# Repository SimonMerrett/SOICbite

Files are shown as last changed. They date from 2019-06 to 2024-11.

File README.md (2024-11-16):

# SOICbite
A compact PCB footprint which allows SOIC test clips to be used as a space-efficient programming and debugging connector

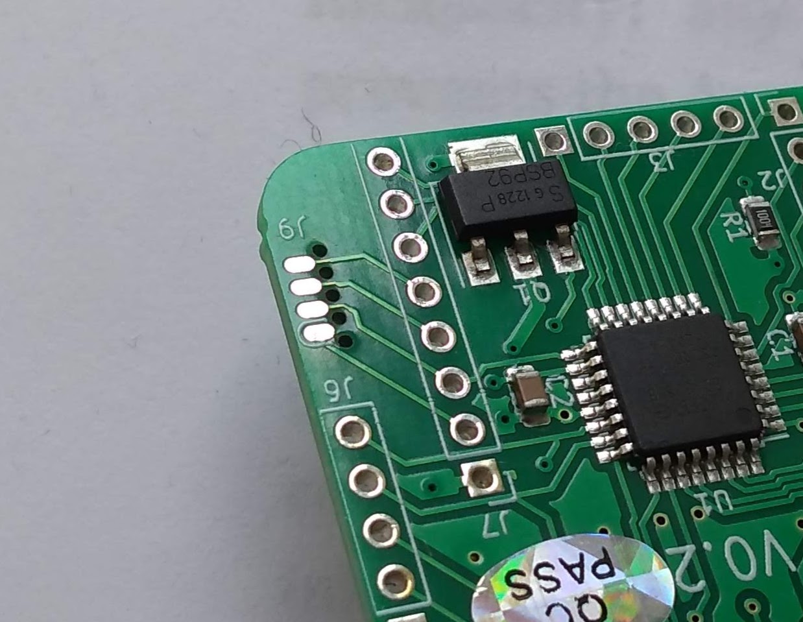
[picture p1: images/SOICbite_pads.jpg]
PBC pads


This is the repository for a hackaday.io project on this connector footprint.

It's cheaper than a Tag Connect and may even be smaller. 

This has been tested as a SPI programmer on AVRs and a UART programmer on ESP32.

The footprints are available in the following formats:

- Kicad (.kicad_mod)
- Eagle XML (.lbr)
- gEDA PCB (.fp)
- pcb-rnd (.lht)

and more formats are welcome.

You do need to [adjust your SOIC-8 test clip](https://github.com/SimonMerrett/SOICbite/blob/master/HOWTO_mod_clip.md) so that it will close enough to press the contact pins against the PCB pads. See the photos in the images folder - about 1mm will do to start with. Depending on your pin configuration, you need to make sure opposing contacts don't touch each other when no PCB is between them. 

Also, you may need to use short sections of thin traces to escape the pads between the NPTH.

# Pin assignment

If you don't know where to start, here are a few suggestions for pin assignments of some interfaces:

| Pin | UART | SPI | SWIM | SWD | ESP8266 | USB | I2C | PIC ICSP | JTAG | SWD + UART |
| --- | ---- | --- | ---- | ----- | --- | --- | --- | --- | ---- | --- |
| 1 | Vcc  | Vcc | Vcc  | Vcc | Vcc | Vcc | Vcc | Vcc | Vcc  | Vcc |
| 2 | RX2  | CS | | | GPIO0 | D-  | | Vpp | TMS  | RX |
| 3 | TX2  | | | | GPIO2 | D+  | | | TCK  | TX |
| 4 | GND  | GND | GND  | GND | GND | GND | GND | GND | GND  | GND |
| 5 | RX | MOSI/MOMI | SWIM | SWDIO | RX | | SDA | DAT | TDI  | SWDIO |
| 6 | TX | MISO | | SWO | TX | | | AUX | TDO  | SWO |
| 7 | CTS  | SCK/CLK | | SWCLK | CH_PD | | SCL | CLK | RTCK | SWCLK |
| 8 | RTS  | RST | NRST | NRST  | RST | ID  | | | NRST | NRST |

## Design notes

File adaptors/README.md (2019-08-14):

# Adaptors

Opinionated boards to breakout the SOICbite connections to standard interface pin arrangements.

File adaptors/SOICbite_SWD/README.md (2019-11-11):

# SOICbite SWD Breakout

SOICbite to SWD breakout board:

1. Standard Cortex Debug connector - VCC, GND, SWDIO, SWCLK, SWO and NRST pins are broken out
2. 4-Pin 2.54" Header - VCC, SWDIO, SWCLK, GND are broken out

## 3D Renders

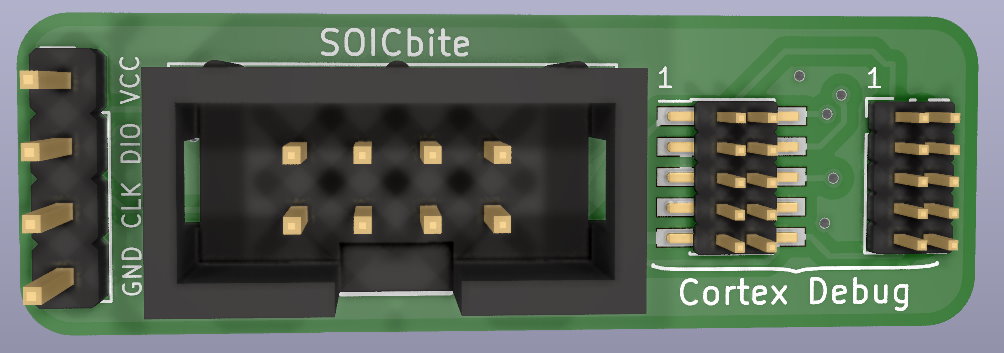
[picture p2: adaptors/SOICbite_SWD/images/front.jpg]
Board front

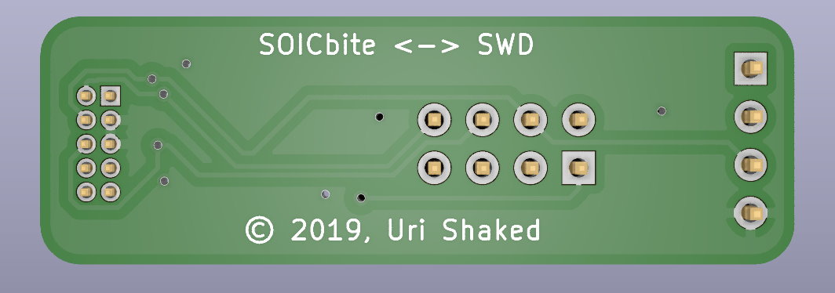
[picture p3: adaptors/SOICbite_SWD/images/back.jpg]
Board back


## Images

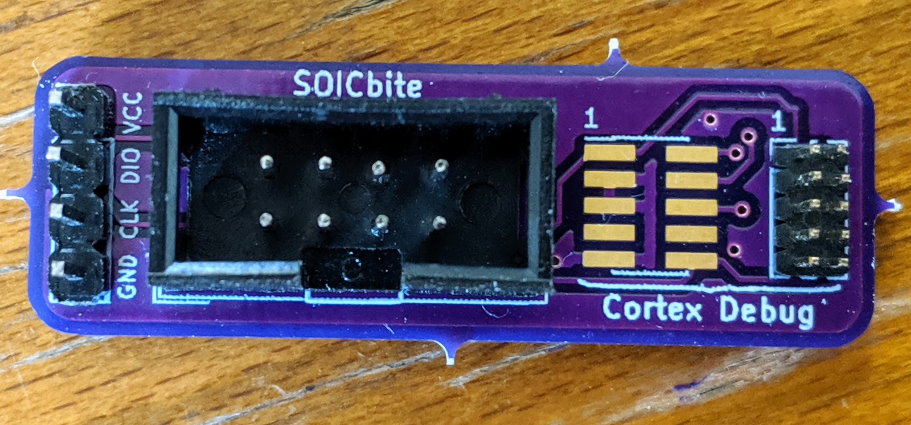
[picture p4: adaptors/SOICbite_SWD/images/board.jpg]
Board image


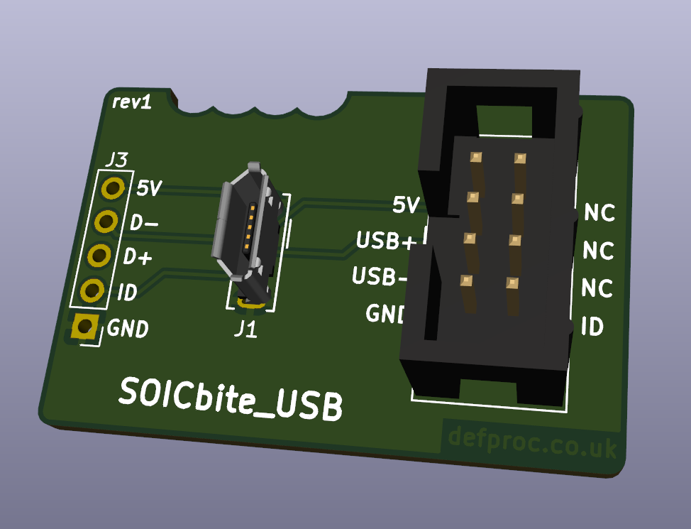
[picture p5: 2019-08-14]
adaptors/SOICbite_USB/images/rev1_3D_front.png

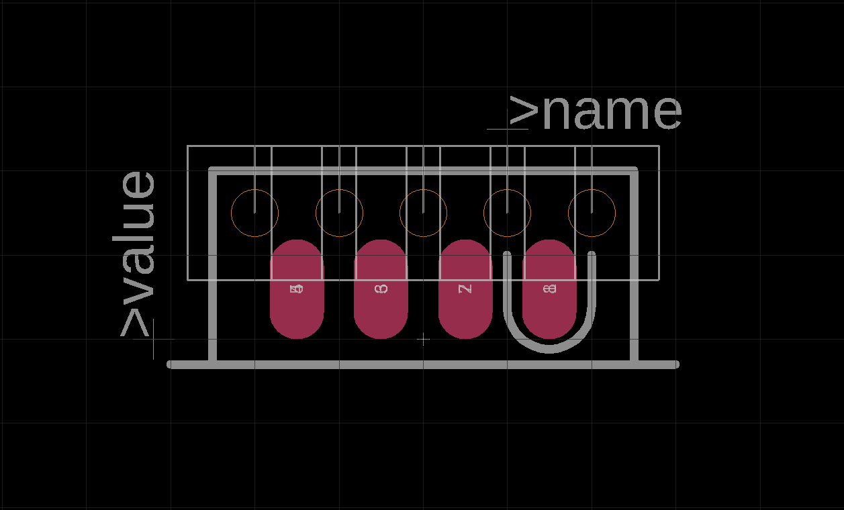
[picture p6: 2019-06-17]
images/Eagle_Footprint.PNG

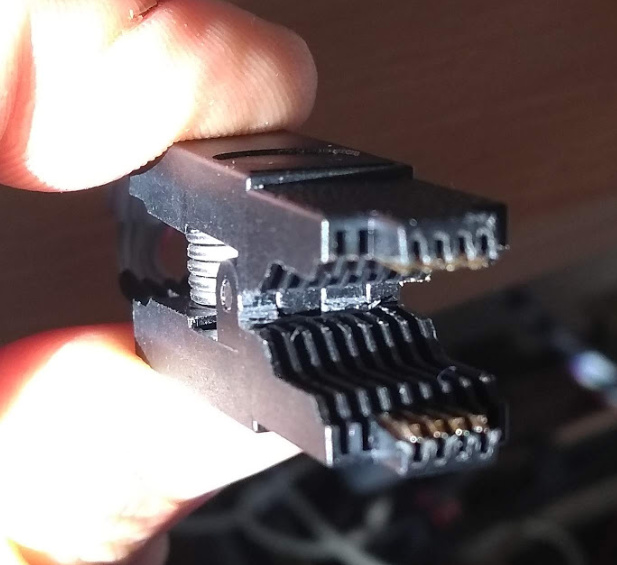
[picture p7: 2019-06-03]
images/slot_cutout_clip.jpeg

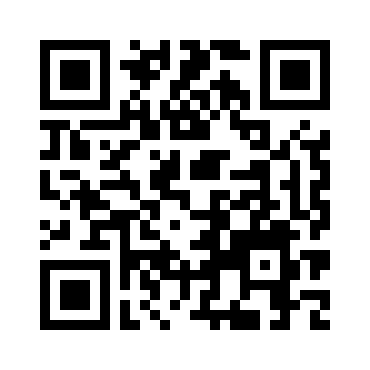
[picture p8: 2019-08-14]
images/github_qr.png

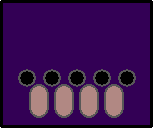
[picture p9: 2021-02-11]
gEDA/images/bottom.png

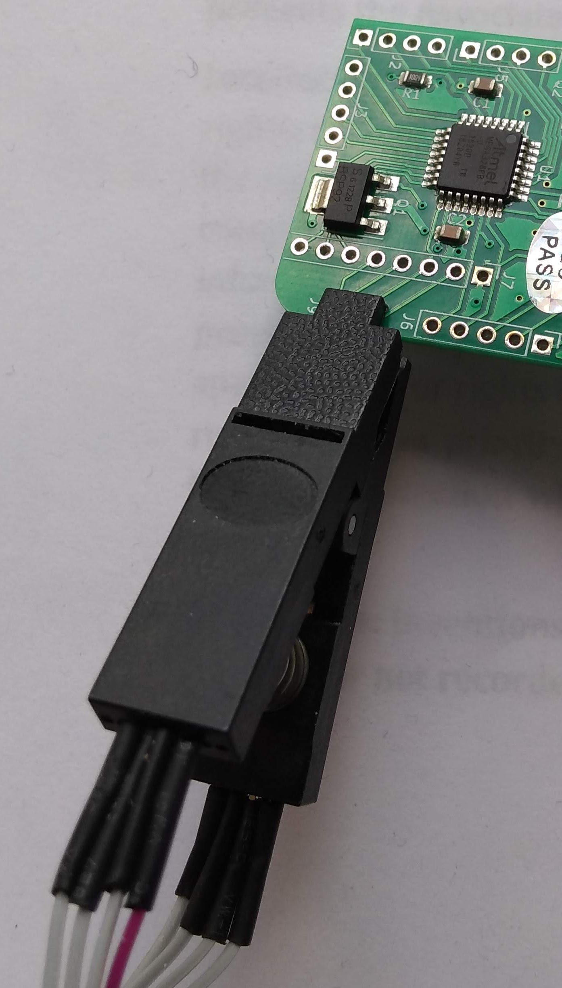
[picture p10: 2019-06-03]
images/SOICbite_connected.jpg

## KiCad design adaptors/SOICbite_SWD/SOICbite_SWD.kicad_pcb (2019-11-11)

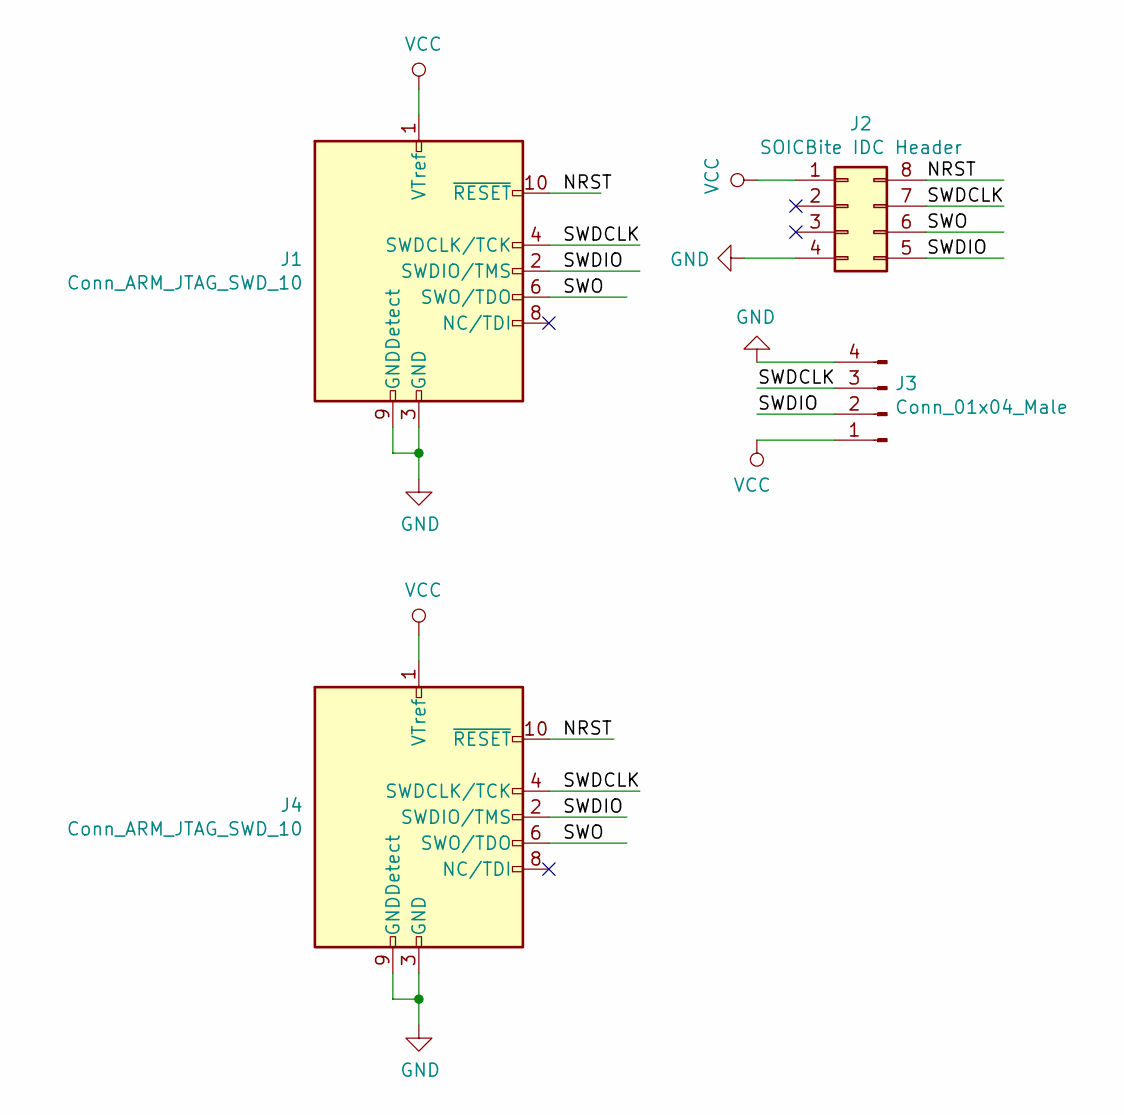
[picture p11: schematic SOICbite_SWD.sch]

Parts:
J1: Conn_ARM_JTAG_SWD_10; PinHeader_2x05_P1.27mm_Vertical_SMD
J2: SOICBite IDC Header; IDC-Header_2x04_P2.54mm_Vertical
J3: Conn_01x04_Male; PinHeader_1x04_P2.54mm_Vertical
J4: Conn_ARM_JTAG_SWD_10; PinHeader_2x05_P1.27mm_Vertical

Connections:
/NRST: J1.10 (~RESET~), J2.8, J4.10 (~RESET~)
/SWDCLK: J1.4 (SWDCLK/TCK), J2.7, J3.3, J4.4 (SWDCLK/TCK)
/SWDIO: J1.2 (SWDIO/TMS), J2.5, J3.2, J4.2 (SWDIO/TMS)
/SWO: J1.6 (SWO/TDO), J2.6, J4.6 (SWO/TDO)
GND: J1.3 (GND), J1.5 (GND), J1.9 (GNDDetect), J2.4, J3.4, J4.3 (GND), J4.5 (GND), J4.9 (GNDDetect)
VCC: J1.1 (VTref), J2.1, J3.1, J4.1 (VTref)

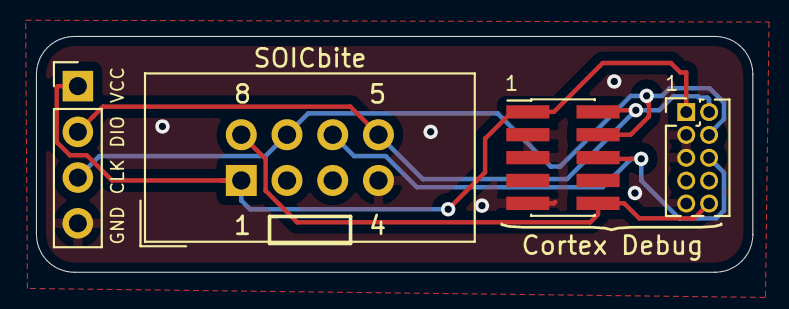
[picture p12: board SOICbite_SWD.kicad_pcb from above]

Board: 2 copper layers, 39.8 x 13.1 mm, 4 parts (0 on the bottom side), 6 nets.

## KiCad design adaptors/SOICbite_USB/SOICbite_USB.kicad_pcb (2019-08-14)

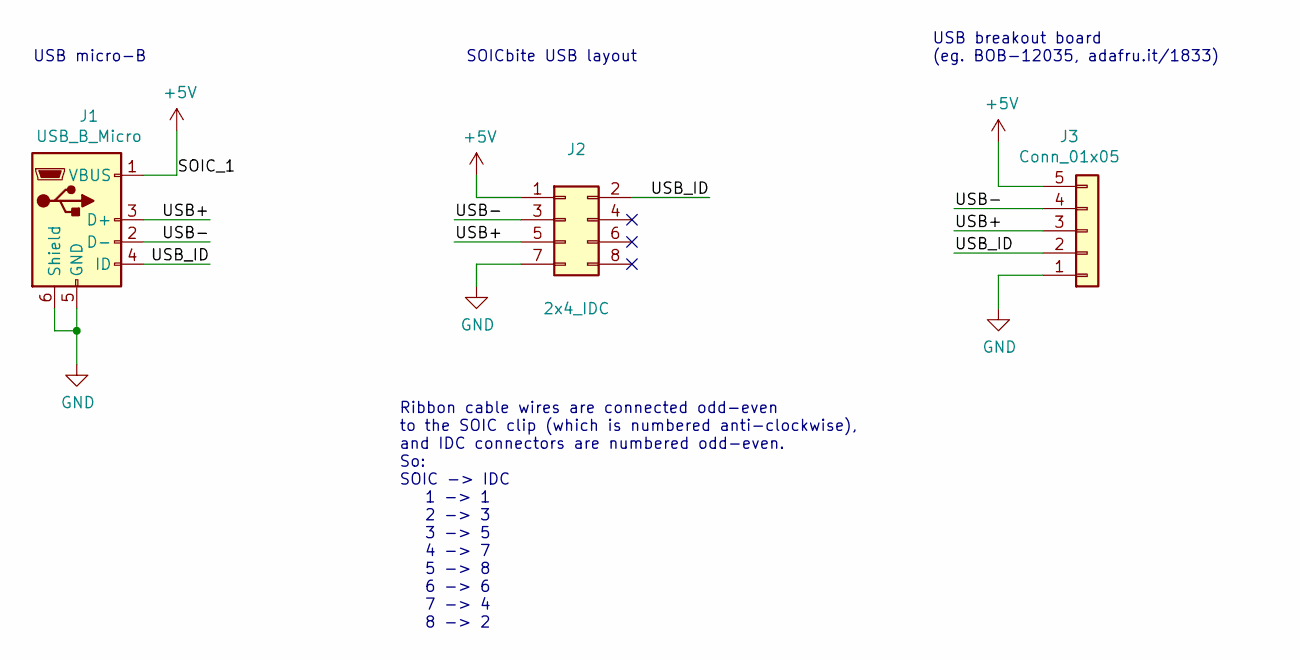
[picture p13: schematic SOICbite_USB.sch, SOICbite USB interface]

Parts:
J1: USB_B_Micro; USB_Micro-B_Wuerth_614105150721_Vertical; MPN 614 105 150 721; farnell 2470821
J2: 2x4_IDC; IDC-Header_2x04_P2.54mm_Vertical; MPN 61200821621; farnell 2356252
J3: Conn_01x05; PinHeader_1x05_P2.54mm_Vertical

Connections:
+5V: J1.1 (VBUS), J2.1, J3.5
/USB+: J1.3 (D+), J2.5, J3.3
/USB-: J1.2 (D-), J2.3, J3.4
/USB_ID: J1.4 (ID), J2.2, J3.2
GND: J1.5 (GND), J1.6 (Shield), J2.7, J3.1

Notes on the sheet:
USB micro-B
SOICbite USB layout
USB breakout board (eg. BOB-12035, adafru.it/1833)
Ribbon cable wires are connected odd-even to the SOIC clip (which is numbered anti-clockwise), and IDC connectors are numbered odd-even. So: SOIC -> IDC 1 -> 1 2 -> 3 3 -> 5 4 -> 7 5 -> 8 6 -> 6 7 -> 4 8 -> 2

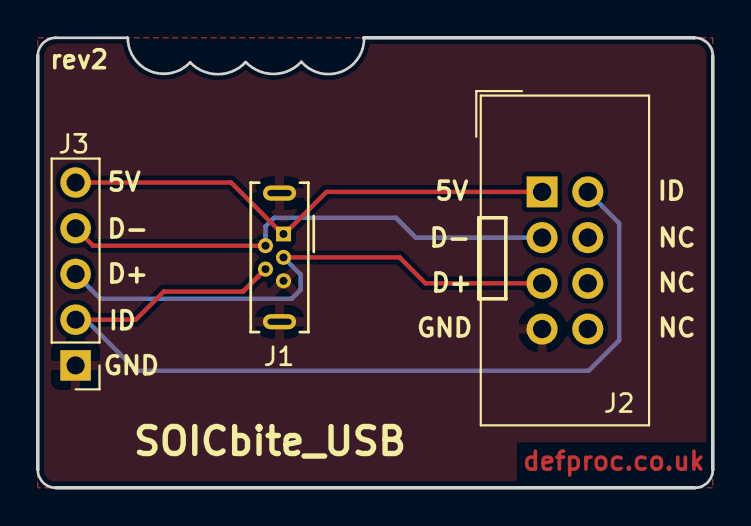
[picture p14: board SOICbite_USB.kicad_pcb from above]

Board: 2 copper layers, 37.5 x 25.0 mm, 3 parts (0 on the bottom side), 5 nets.

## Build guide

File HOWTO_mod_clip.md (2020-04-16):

## HOW TO MODIFY YOUR SOIC CLIP ##
It is fairly easy to modify the plastic part of the clip by trimming / shaving small amounts of plastic away using a craft knife or other sharp blade
This picture is intended to be a helpful reference to show what is required.
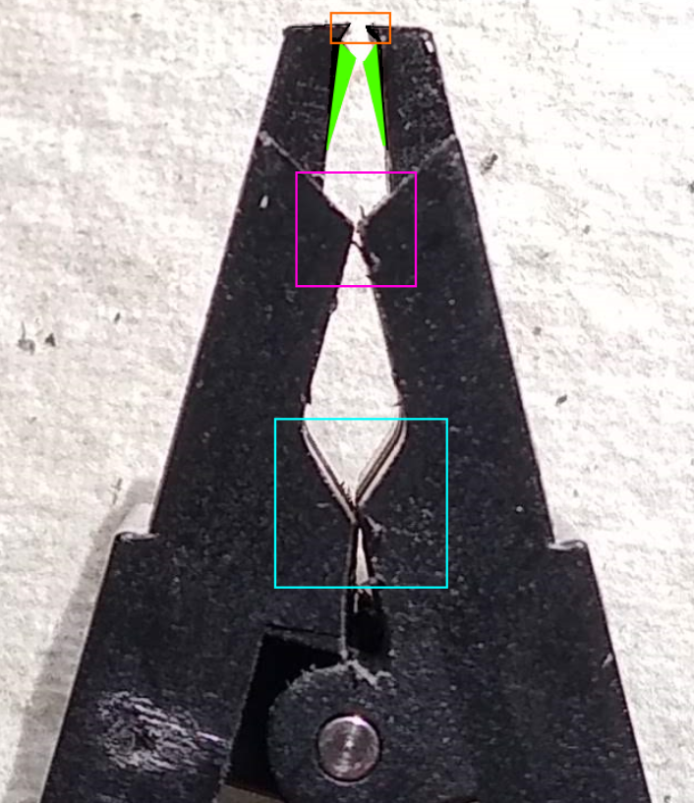
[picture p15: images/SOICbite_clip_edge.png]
SOIC clip edge profile

* The green is highlighting where the spring contacts are, for contrast.
* Be aware that depending on your pin configuration, it may be a bad idea to let the opposing contacts touch each other when no PCB is mounted! So take care when you are trimming plastic not to take too much off in one go.
* The plastic in the cyan box is the main area which needs to be trimmed.
* Depending on the moulding of your clip, you may also need to trim plastic in the magenta box.
* The claws which locate the clip in the PCB holes are in the orange box. Normally they would not be amended but a flex cable may require removing _**one** pin from an opposing **pair**_, to allow the clip to press its contacts down on the pads adequately.

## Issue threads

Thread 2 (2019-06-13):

Prevent reverted connection

X-Ryl669, 2019-06-13:
Nice work!

If, instead of the 5 holes after the contact pin, you fill one of them (for example, the 2nd one to the top) and cut the matching plastic part on the grip, you have revert connection protection.
It's even probably cheaper since that make one less hole to drill on the PCB.

This worth it if you intend to reprogram your device few month later and don't want to spend time figuring out the pinout of the SOICbite's connection, or if you have (unskilled) workers programming board in series.

SimonMerrett, 2019-06-14:
If you look in the side profile of the SOIC clip I modified in the [project photos](https://github.com/SimonMerrett/SOICbite/blob/master/images/slot_cutout_clip_side.jpeg), you'll see that the spring conductors of the clip are closer to the PCB, so I don't think this keyed design would save you from VCC touching the wrong pads but visually it might help you line stuff up.

There is a silkscreen half loop around pad 1, which can be lined up with the red index wire coming out of the SOIC clip, or you could even mark the SOIC clip plastic itself.

FWIW, I unplug my IDC connector on the other end of the ribbon cable, then connect the SOICbite and then replug the IDC in.

I'm happy to keep this issue open if you want to submit a version that is keyed, otherwise I'll close. Please let me know.

X-Ryl669, 2019-06-14:
Not sure I'm getting what you are saying. In the file SOICbite_connected.jpg, it seems like you've printed a plastic part that enclose the clip to target the 5 holes in the PCB. I thought you could print 4 pins instead of 5 (in the layout like this: ` o   o o o`) and have the same in the PCB. If you don't have a plastic part enclosing the clip, then I'm confused about the use of the 5 holes in the PCB. What are they for ?

SimonMerrett, 2019-06-14:
I haven't printed any plastic parts, just used an off-the-shelf SOIC-8 test clip and sliced some of the jaws in the centre so it will close tight enough for the clip's metal (sprung) contacts to touch the PCB pads.
The holes in the PCB are for the small claws on the SOIC clip to grip onto. This is for alignment and mechanical hold, but the reality is with at least the SOIC clip that _I have_ is that the metal contacts will touch the PCB even if there were no holes for the claws to sink into. So although your idea would give you some indication that you were correctly orientated (if incorrect, one claw would be holding each side of the jaw clear of the PCB and the clip could easily be pulled off, in theory), I don't think it would stop you from accidentally connecting pads to contacts the wrong way around. Would love a solution to this but the current suggestions of removing holes and claws doesn't seem to achieve this _with the gear that I have_. YMMV, so please try and let me know. There is an advantage of removing some holes and claws, which is that you can keep thicker traces to escape the pads.

SimonMerrett, 2019-06-15:
Hi @X-Ryl669 closing now as no reply - feel free to re-open if needed.

X-Ryl669, 2020-06-16:
I've made some change to your solution [here](https://github.com/X-Ryl669/SOICconnect). I'm printing a small plastic part that's ensuring the position and prevent inverted connection. It's also helping for connection since it gives a physical feedback with some border to push the PCB edge onto and a fang to laterally center.

If you have a 3D printer, it's a 10mn print time that'll save your board from shifted pin connections.

Closed 2019-06-15.

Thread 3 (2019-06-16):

SWD pinout

rewolff, 2019-06-16:
I'm an STM32 user, so I use the SWD connector. (not yet this project).

I am not aware of the "SWO" pin in that configuration....

The "discovery" boards also have the target NRST signal connected on the programming connector. there is a spot available for that -> do it.... (possibly mark as optional... )

The "discovery" boards have a 6-pin connector and I have been unable to find what the 6th was ever intended for.
I have now repurposed that for the "boot0" signal. With a pulldown to GND and a switch to VCC I can then boot the target into bootloader mode.

I suggest to mark one of the further free pins for that purpose. Then, I'd be able to have two of the clamps, one on my programmer and one to a two-switch-board that allows me to hit the boot,  and reset buttons to make the target switch to bootloader mode. (=DFU over USB for most of my targets).

SimonMerrett, 2019-06-17:
That'd be fine by me - please submit a pr so I can see exactly what you want.

rewolff, 2019-06-17:
Will do. Creating eagle layout now.

SimonMerrett, 2019-06-17:
Thanks. Will you leave the pin assignments on the eagle footprint unlabelled so that it can be used for any pin configuration? Would prefer to leave pin assignment conventions in the Readme.md for now. Fantastic to have an eagle footprint though - much appreciated.

rewolff, 2019-06-17:
Eagle has "sub-devices" that can have different footprints. e.g. for a soic/dip version of a chip. I was hoping to do it the other way around, but alas, that's not possible. So for now I have a "generic soicbite" that in the symbol simply exports pin 1, pin2 etc..
Later: application specific schematic symbols that export the pinout for a specific CPU so that it's easy to hookup correctly for that specific CPU/family.

SimonMerrett, 2019-06-17:
@rewolff , does https://github.com/SimonMerrett/SOICbite/blob/master/SOICbite_Eagle.lbr help? Thanks to @VoswijkC

Closed 2019-06-17.

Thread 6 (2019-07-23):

Converter boards

DefProc, 2019-07-23:
Do you have thoughts on generating converter boards that go from the SOIC clip standard IDC connectors to protocol specific interfaces eg. typical USB/UART module pinout?

I'm aware that this might move SOICbite away from a more connection agnostic solution, but the table of suggested connection pins in the Readme was really good from my point of view, it lets me just take the connection I want to add, and route to a pad arrangement that already exists, instead of having to create new ones each time, eg. [xkcd.com/927](https://xkcd.com/927/).

I've forked a repo at [DefProc/SOICbite](https://github.com/DefProc/SOICbite/tree/master/converters) with a USB converter I'm trying as an example.

SimonMerrett, 2019-07-29:
@DefProc sorry not to have replied sooner. I do this kind of board for my programmers already but I really like your USB version! Have you built/tested it yet? I was particularly pleased with the 2MHz default SWD clock with my Atmel ICE working with a relatively bodged and elongated cable/connector arrangement last week.

SimonMerrett, 2019-07-29:
@DefProc but to more specifically answer your question:

1. My first thought is that making converter/adapter boards is a good idea that compliments the SOICbite concept.
2. How to add value? Perhaps including good pinout labelling on the silkscreen? Maybe a voltage regulator in some cases (I'm thinking how the FTDI boards don't have sufficient current from 3.3V pin for the ESP range of chips). Good mechanical design with mounting holes as a minimum for "nailing" to the bench but perhaps even a second layer of PCB that acts as a "lid" held on standoffs, with cutouts for the connectors. Possibly the option to have a separate power supply (jumper bridge to select source) to the IC, rather than e.g. the USB 5V pin? Could be good for testing lower voltages etc?

DefProc, 2019-07-31:
@SimonMerrett I've got some [boards in the post from Aisler](https://aisler.net/p/CMPNOGUJ), I'll let you know how testing goes.

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

Yes for good pin labelling, I really like it when boards can be self documenting, even if it means taking a little more space. Doubly for development boards.

It feels like it's worth adding a feature if it solves a problem that you have when using an interface normally. Although I'm a bit fan of the Unix philosiphy of "do one thing well"; if the IDE connector is standard enough that it could be reasonable to apply a specific function to a specialist connection board (eg. [USB power injector](https://www.tindie.com/products/mux/usb-datapower-merger-anti-splitter/)) rather than trying to have one board to all possible jobs for an interface.

Do you have a preferred standard for spacing/sizing of mounting holes? M3 clearance holes on a metric spaced grid? Are you trying to "nail" it other existing hardware?

Is it worth selecting some standard measurements to allow anyone to expand from based on need?

SimonMerrett, 2019-08-01:
> Do you have a preferred standard for spacing/sizing of mounting holes? M3 clearance holes on a metric spaced grid? Are you trying to "nail" it other existing hardware?

I think M3 makes sense as a very common standoff dimension. I'd go so far to suggest we ought to seek multiples of 2mm or 5mm as the grid pitch. I'm not attaching to anything specific - it's just something we would wished we had included if we omit it! But I don't think this is necessary to use SOICbite - just suggestions if you don't have a better starting point. As you say, I think self-documenting boards/pins are the most important bit. That way there is minimum likelihood of magic smoke release if someone picks up and connects the wrong adapter board.

Nice board - I like the "bite" in the outline!

SimonMerrett, 2019-08-01:
So if your test goes well with this board, shall we have an "adapter board" folder in the main repo?

DefProc, 2019-08-05:
Sure, that's all working as expected. I'll open a pull request to add the boards in a subfolder.

SimonMerrett, 2019-08-12:
Hi, sorry for the delay. I'm getting back into things this week after holiday. Will get to the pr as soon as I can.

SimonMerrett, 2019-08-14:
Commit #7 should let us close this for now.

Closed 2019-08-14.

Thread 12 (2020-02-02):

'Known good' SOIC Clip

joshtyler, 2020-02-02:
I've designed this connector into a PCB, I think it's quite a neat solution - thank you for designing it.

Unfortunately the SOIC clip I used was a bit flimsy, and so never made very good contact with the PCB, and before long the plastic guide pins broke.

I was wondering therefore if you had the model number of a SOIC clip that was easy to modify, and worked reliably?

SimonMerrett, 2020-02-02:
@joshtyler I'm afraid I have just been lucky with the cheapest of the cheap from eBay/Aliexpress etc. Let's keep this issue open for a while and see if anyone else has any tips for clips they'd recommend as it would be good to have one people could rely on a bit more.

whinis, 2020-04-29:
I have been using this one https://smile.amazon.com/Signstek-SOIC8-Socket-Adpter-Programmer/dp/B00V9QNAC4. Requires modifying as normal but clips fairly strongly. You can remove the center pin and stretch the spring a bit for an even strong clip

v01d, 2020-05-17:
Have you thought about designing something for 3D printing? Would mostly require an equivalent spring and contacts (maybe it could be designed for standard pin headers, after removing their plastic housing). This way the teeth could be made to grab the PCB before the pads are contacted

janmg, 2021-04-06:
The cheap black soic8 clamps seem to use weak plastic, so they can be used ten to twenty times but then their spring will crush the guides. I got mine for $0.70, so next time I need them, I'll invest in these more rigid looking test clips, I haven't tried them yet though.

CPT-063 Test Clip SOIC8 Pomona 5250
https://www.pomonaelectronics.com/products/test-clips/soic-clip-8-pin

SimonMerrett, 2021-04-06:
> but then their spring will crush the guides

Interesting - I haven't experienced this but not done many tens of use cycles. Please do update us with what you find when you get the other clips.

SimonMerrett, 2021-04-06:
> Have you thought about designing something for 3D printing?

No but open to suggestions. There are quite a few decent clothes-peg type custom clips out there, often built from PCB/Acrylic and pogo pins.

2nOrderEDO, 2024-09-25:
Hello Simon, thanks for the SOICbite idea, it really is very cool.

I had the chance to test it some days ago. At the beginning I faced problems with the clips not making contact with the pads. It significantly improved after stretching the spring out to increase the clipping force. Nevertheless, this did not solve all issues.

After careful inspection, I noticed the metal pins on my SOIC clip were very slightly out of the plastic. I also confirmed this was the case when comparing my clip with yours [here](https://github.com/SimonMerrett/SOICbite/blob/master/HOWTO_mod_clip.md)

It turns out it is possible to move in and out the pins by applying some force with pliers. After aligning the contact point of the pins over the pads, the clip is working flawlessly.

I propose to add a note like below to the documentation:

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

Regards,
2nOrderEDO

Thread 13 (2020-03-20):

No license

davidlenfesty, 2020-03-20:
Thanks for putting this out there :).

I'm putting this into my personal KiCAD library, which I plan on throwing up on github, but I would feel weird putting it up without some sort of attribution, or confirmation that that is okay with you in some way.

It's really not necessary but I do suggest putting a license file somewhere, may I suggest BSD, or the [WTFPL](http://www.wtfpl.net/).

SimonMerrett, 2020-03-20:
@davidlenfesty you're right and I just couldn't be bothered to read the differences and choose one when I set up the repo.
It's certainly OK for you to include in your publicly hosted kicad library. Attribution would be appreciated but I don't consider it necessary as I haven't given anyone else who has built converter boards etc the impression that they ought to attribute.
The only licence clause I could think is relevant is the usual disclaimer about being fit for purpose and provided as-is with no guarantee etc. If you know one that covers that (and perhaps also attribution if you can't find one standalone) please let me know which one it is and I'll add it. But otherwise crack on!

davidlenfesty, 2020-03-28:
The [2-clause BSD license](https://opensource.org/licenses/BSD-2-Clause) is the closest and simplest thing I could find.

It does require attribution but that just means copying the license file essentially.

SimonMerrett, 2020-03-28:
@davidlenfesty thanks for the research. License added!

Closed 2020-03-28.

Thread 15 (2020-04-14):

Flex restrictions

edoput, 2020-04-14:
Hello and thank you for this nice project.

I'm thinking of doing a flex PCB for running some UART lines out of a device case but
I'm stuck on how to later connect to the extension from a UART-USB adapter.

This looks promising as it is dead easy and does not require me to place a new connector (SMT or TH), hell I could reuse any SOIC clip lying around.

Let's say we use [OSH Park](https://docs.oshpark.com/services/flex/) and work along some limits.

Obviously we need solder mask on both side of the PCB but that is covered

>  Soldermask Type | SMOBC (Soldermask Over Bare Copper), both sides

We also need two layers of copper and that is also covered.

So the real question is if we can actually find a SOIC connector that can clamp this
extremely thin PCB as the stackup is the following.

| Layer | Thickness |
| -- | -- |
Silkscreen | 1mil (0.0254mm) | +/-0.2mil (0.00508mm)
Soldermask | 1mil (0.0254mm) | +/-0.2mil (0.00508mm)
Top Copper | 1oz  (1.4mil, 35um) |  
Polyimide Flexible Substrate | 4mil (0.1016mm) | +-0.4mil (0.0102mm
Bottom Copper | 1oz  (1.4mil, 35um) |  
Soldermask | 1mil (0.0254mm) | +/-0.2mil (0.00508mm)
Silkscreen | 1mil (0.0254mm) | +/-0.2mil (0.00508mm)

Which would yeld a total of 10.8 mil ( ~ 0.25 mm).

So maybe just one side would be available at a time, the other covered by some *thickening* to make the connection more reliable as otherwise the film might just slip out all the times.

We also have some restrictions on how far from the edge copper should be as the process
of cutting it's different from rigid material.

> *Board Edge Keepout* Copper within 15mil (0.381mm) of a board edge will be fabbed,  but may be damaged during shipping, copper within 6mil (0.152mm) of a board edge will be  removed prior to fabrication

So overall if the connector is not placed very close to the border it should survive the fabrication process and the SOIC clip can still reach it.

I'm interested in the drill holes as for [flex pcb there are different limits](https://docs.oshpark.com/services/flex/#drill-specifications) and the wear and tear might be different.

Is there any other physical requirement for this connector that I haven't gone over?

SimonMerrett, 2020-04-14:
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
Hey @edoput , from a quick and dirty look, you will need to cut away the plastic in the cyan box in the image above (the green represents the spring contacts, for contrast), which everyone needs to do unless using *very* thick PCB substrate. I also think in your case, you may need to cut away some plastic in the magenta box. Looking at the "claws" in the orange box and thinking about your requirements, you may want to cut away one of each opposing pair of claws, so that they interleave and still lock onto the holes, overall. You could just cut away one side of claws but this may not line the pads up with the spring contacts evenly.

If I leave this issue open, will you try something out and let us know what works?

edoput, 2020-04-14:
I didn't know it would generally require modifications to the clip, good to know.

I'm looking for more off the shelf solutions (just running a flex cable with more pins that I need) but if
I ever get around to designing my flex pcb I'll put it on and see if it works.

SimonMerrett, 2020-04-16:
I'll close the issue then. Feel free to reopen if you have anything to report.

Closed 2020-04-16.

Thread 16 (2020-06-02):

Recommanded distance to board edge

X-Ryl669, 2020-06-02:
I'm finally trying to implement this footprint on one of my board, and I'm wondering what is the best expected distance from board edge ?

In the connector footprint, there's an inverted T on the bottom, but I just wanted to be sure it's meaning it's supposed to match the board edge:
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

Can you confirm ?

SimonMerrett, 2020-06-02:
Yes, that lower "baseline" in the image is supposed to be a guide to line up with the board edge. You could place it further into the board (limited by the "throat" of your clip) but this is probably the best compromise between being unobtrusive and relatively stable when the clip is connected.

SimonMerrett, 2020-06-02:
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

X-Ryl669, 2020-06-03:
Thanks! Very useful.

Closed 2020-06-03.

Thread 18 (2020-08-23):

SWD: 5V pin?

dbrgn, 2020-08-23:
I'm creating SOICbit footprints and components for https://librepcb.org/, in order to connect an ARM based board to an SWD debug probe (JLink).

JLink offers a (non-standard?) 5V pin on the connector (power from USB) that can be turned on via software: https://www.segger.com/products/debug-probes/j-link/technology/interface-description/#swd-connector-pinout Do you think we could put it on pin 2 or 3, to get some kind of standardization?

SimonMerrett, 2020-08-23:
I have no problem with that. I should say that the suggestions on the Readme.md are not standards, merely suggestions. But I also appreciate that suggestions can become standards through convention and inertia. Will you submit an amended Readme.md with the PR for the Librepcb footprint files? I acknowledge that Librepcb is less dependent on Github repos for footprints - but it would be nice to host them here too.

dbrgn, 2020-08-23:
Yes, I can open a PR!

LibrePCB libraries should usually be repositories themselves (for easier checkout), but I can submit a file with a link to the library repo (https://github.com/dbrgn/SOICbite.lplib).

SimonMerrett, 2020-08-23:
thanks for the link. I'm not an expert on licenses but you seem to have a different one than the one used for SOICbite. Is that compatible?

dbrgn, 2020-08-24:
CC0 is essentially public domain, so it's compatible with any license! It means "no restrictions or guarantees whatsoever".

SimonMerrett, 2020-08-24:
But no attribution. It's interesting as I don't really think copyright comes into play if you use a different file format to generate the same footprint in copper etc and you have linked to the original repo so there is kind of attribution there. But you don't impose attribution on anyone who copies your code. I'm not bothered about attribution to a large degree - the main reason I added a license was because someone asked for it. Just interesting to see how a license does or does not affect things! :-)

dbrgn, 2020-08-24:
CC0 is the recommendation for all LibrePCB libraries, since LibrePCB should be usable for commercial projects as well, and a project always contains the library elements. If you want to do a commercial project and include a library element that requires attribution, dealing with this in a legally correct way is probably quite tricky.

It seems that most people simply ignore this issue when using licenses with attribution requirements :slightly_smiling_face:

Closed 2020-08-23.

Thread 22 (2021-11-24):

Suggested pinouts

zharijs, 2021-11-24:
Hi again.

I suggest 2 more pinouts - combination of SWD + UART + FactoryMode detection and same for PIC. They're already presented in my libs. I use these combos in my projects, so I can get debugger, console and FactoryMode detection from single connector speeding up the manufacturing process and making R&D space cleaner. FactoryMode is just GPIO with pull-up, that is pulled down by the programming clip and makes the device enter init / test sequence after boot automatically.

Here are my pinouts:
PIN  |  SWD  |  PIC
1 - VCC - VCC
2 -  GND - GND
3 - NRST - MRST
4 - SWDIO - PGD
5 - SWCLK - PGC
6 - RXD - RXD
7 - GND/FM -GND/FM
8 - TXD - TXD

DeflateAwning, 2024-11-02:
As a markdown table:

```
| PIN | SWD   | PIC     |
|-----|-------|---------|
| 1   | VCC   | VCC     |
| 2   | GND   | GND     |
| 3   | NRST  | MRST    |
| 4   | SWDIO | PGD     |
| 5   | SWCLK | PGC     |
| 6   | RXD   | RXD     |
| 7   | GND/FM| GND/FM  |
| 8   | TXD   | TXD     |
```

| PIN | SWD   | PIC     |
|-----|-------|---------|
| 1   | VCC   | VCC     |
| 2   | GND   | GND     |
| 3   | NRST  | MRST    |
| 4   | SWDIO | PGD     |
| 5   | SWCLK | PGC     |
| 6   | RXD   | RXD     |
| 7   | GND/FM| GND/FM  |
| 8   | TXD   | TXD     |

For the SWD+UART version, why didn't you add the two UART lines into the existing SWD pinout. That seems far more sensible?

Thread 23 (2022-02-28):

Trace width?

milkpirate, 2022-02-28:
Hey,

nice work! Whats the max. resaonable trace width to route between the inner pads?

DeflateAwning, 2024-11-02:
Assuming you're getting JLCPCB (or a manufacturer with similar capabilities to make it), here's what I've found.

### JLCPCB Capabilities
* NPTH to Track: 0.2mm
* Min Trace Width: 0.1mm

(NPTH = Non-Plated Through Hole, aka Mechanical Hole)

### KiCAD Settings
* Set **"Copper to Hole Clearance" to 0.2mm**
* Use wide traces for the outer pads (e.g., 0.25mm), especially for power.
* Use **0.15mm traces** for passing between the mechanical holes.

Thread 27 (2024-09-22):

feature request: 3.3v combo pinouts - UART and I2C

makergamer, 2024-09-22:
I really like the smart and simple use of the edge test pads.

I really don't like deviating from defined standards - especially ones that are 5 years old. Recently finding this, I could an additional combo (although a deviation). Like the ESP8266 (combines UART & 2 GPIO), most microcontrollers for sensor work leverage 3.3v UART & I2C as the SDIO is for SD Cards.

I'm free to do this with my own projects, but I thought I would share this observation.

```
Pin   3.3v UART + I2C
1     Vcc
2     SDA
3     SCL
4     GND
5     RX
6     TX
7     CTS
8     RTS
```

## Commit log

2019-06-03 Upload SOICbite kicad_mod footprint file
2019-06-13 Purpose a pin assignment
    This is just a starting point to suggest a pin assignment for this
    connector. It would be great if every project with a SOICbite connector
    could be used similar, with the same programmer. Anyhow, a "version 1"
    probably should be discussed somehow with all the pros and cons. This
    one uses the SPI pinout of an AVR AT-Tiny and tries to assign similar
    functions from other interfaces to the same pins.
    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
2019-06-14 Swapping pin 1 - pin 8
2019-06-17 Recreated Footprint within Eagle along with a simple Symbol for EAGLE users in .lbr form. Review added images for footprint and library/component description
2019-06-17 Typo correction. Footprint cleanup.
2019-07-23 SOICbite to USB converter board, rev1
    [SOICbite_USB-B.Cu.gbr, SOICbite_USB-B.Mask.gbr, SOICbite_USB-B.Paste.gbr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]
2019-07-23 include render of USB interface board
2019-08-02 rev1 of a plain IDC to UART adaptor
    [UART_plain-B.Cu.gbr, UART_plain-B.Mask.gbr, UART_plain-B.Paste.gbr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]
2019-08-05 SOICbite_USB is works in testing, moved UART_plain to wip directory, kicad gitignore
    [SOICbite_USB-B.Cu.gbr, SOICbite_USB-B.Mask.gbr, SOICbite_USB-B.Paste.gbr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]
2019-08-13 removed wip, moved to wip_uart branch
    [UART_plain-B.Cu.gbr, UART_plain-B.Mask.gbr, UART_plain-B.Paste.gbr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]
2019-08-13 rev2 layout, moved USB_ID to SOICbite pin 8
    [SOICbite_USB-B.Cu.gbr, SOICbite_USB-B.Mask.gbr, SOICbite_USB-B.Paste.gbr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]
2019-08-13 revised pinout, D- should be by Vcc
    [SOICbite_USB-B.Cu.gbr, SOICbite_USB-B.Mask.gbr, SOICbite_USB-B.Paste.gbr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]
2019-08-13 and update the silkscreen to match the D+/D- swap
    [SOICbite_USB-B.Cu.gbr, SOICbite_USB-B.Mask.gbr, SOICbite_USB-B.Paste.gbr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]
2019-09-28 Added suggested pinout for I2C
2019-09-29 Add SOICbite to SWD adaptor board
    [SOICbite_SWD.kicad_pcb, SOICbite_SWD.sch]
2020-06-02 Upload drawing to indicate board edges
    Careful - these dimensions have yet to be fully confirmed but you should be fine using them to make your own footprint from.
2020-06-20 kicad: add courtyard around symbol
    It is good to have courtyard defined as DRC might use it to catch errors
    when components are missing. While it doesn't sound that useful for this
    particular part, the DRC might actually complain about it being missing
    if its turned on for the project.
    The courtyard layer is defined on:
    https://kicad-pcb.org/libraries/klc/F5.3/
    This patch adds the front and back courtyard with the same contour as on
    the fab layer.
2021-02-11 add gEDA footprint and symbol
2021-02-11 add gerbers and images for gEDA footprint
    [SOICbite.bottom.gbr, SOICbite.bottommask.gbr, SOICbite.bottompaste.gbr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]
2022-04-21 Add footprint for pcb-rnd
2023-11-25 Add JTAG pin specification
2024-11-02 Add SWD+UART pin assignment
2025-08-10 Add UPDI pinout
    Modify UART pinout to put UPDI on RX pin

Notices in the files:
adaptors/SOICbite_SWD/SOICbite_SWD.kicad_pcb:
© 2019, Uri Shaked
